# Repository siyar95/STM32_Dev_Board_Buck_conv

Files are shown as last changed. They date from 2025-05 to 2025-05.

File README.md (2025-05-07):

# STM32 Dev Board – Project 2

This project is a custom **development board** designed around the **STM32F405RGT** microcontroller.  
It includes the essential peripherals for firmware development and prototyping:

## 🔧 Features

- **STM32F405RGT** ARM Cortex-M3 microcontroller
- **USB (Device/Power)**
- **UART** interface for serial communication
- **SWD (Single Wire Debug)** header for programming and debugging
- **I2C** interface for peripheral communication
- **Buck converter** for stable and effecient 3.3V power supply

## 🧱 PCB Stackup

This project uses a 4-layer PCB design:

1. **Top Layer (Layer 1)** – Signal  
2. **Inner Layer 1 (Layer 2)** – Ground (GND)  
3. **Inner Layer 2 (Layer 3)** – 3.3V Power Plane  
4. **Bottom Layer (Layer 4)** – Signal








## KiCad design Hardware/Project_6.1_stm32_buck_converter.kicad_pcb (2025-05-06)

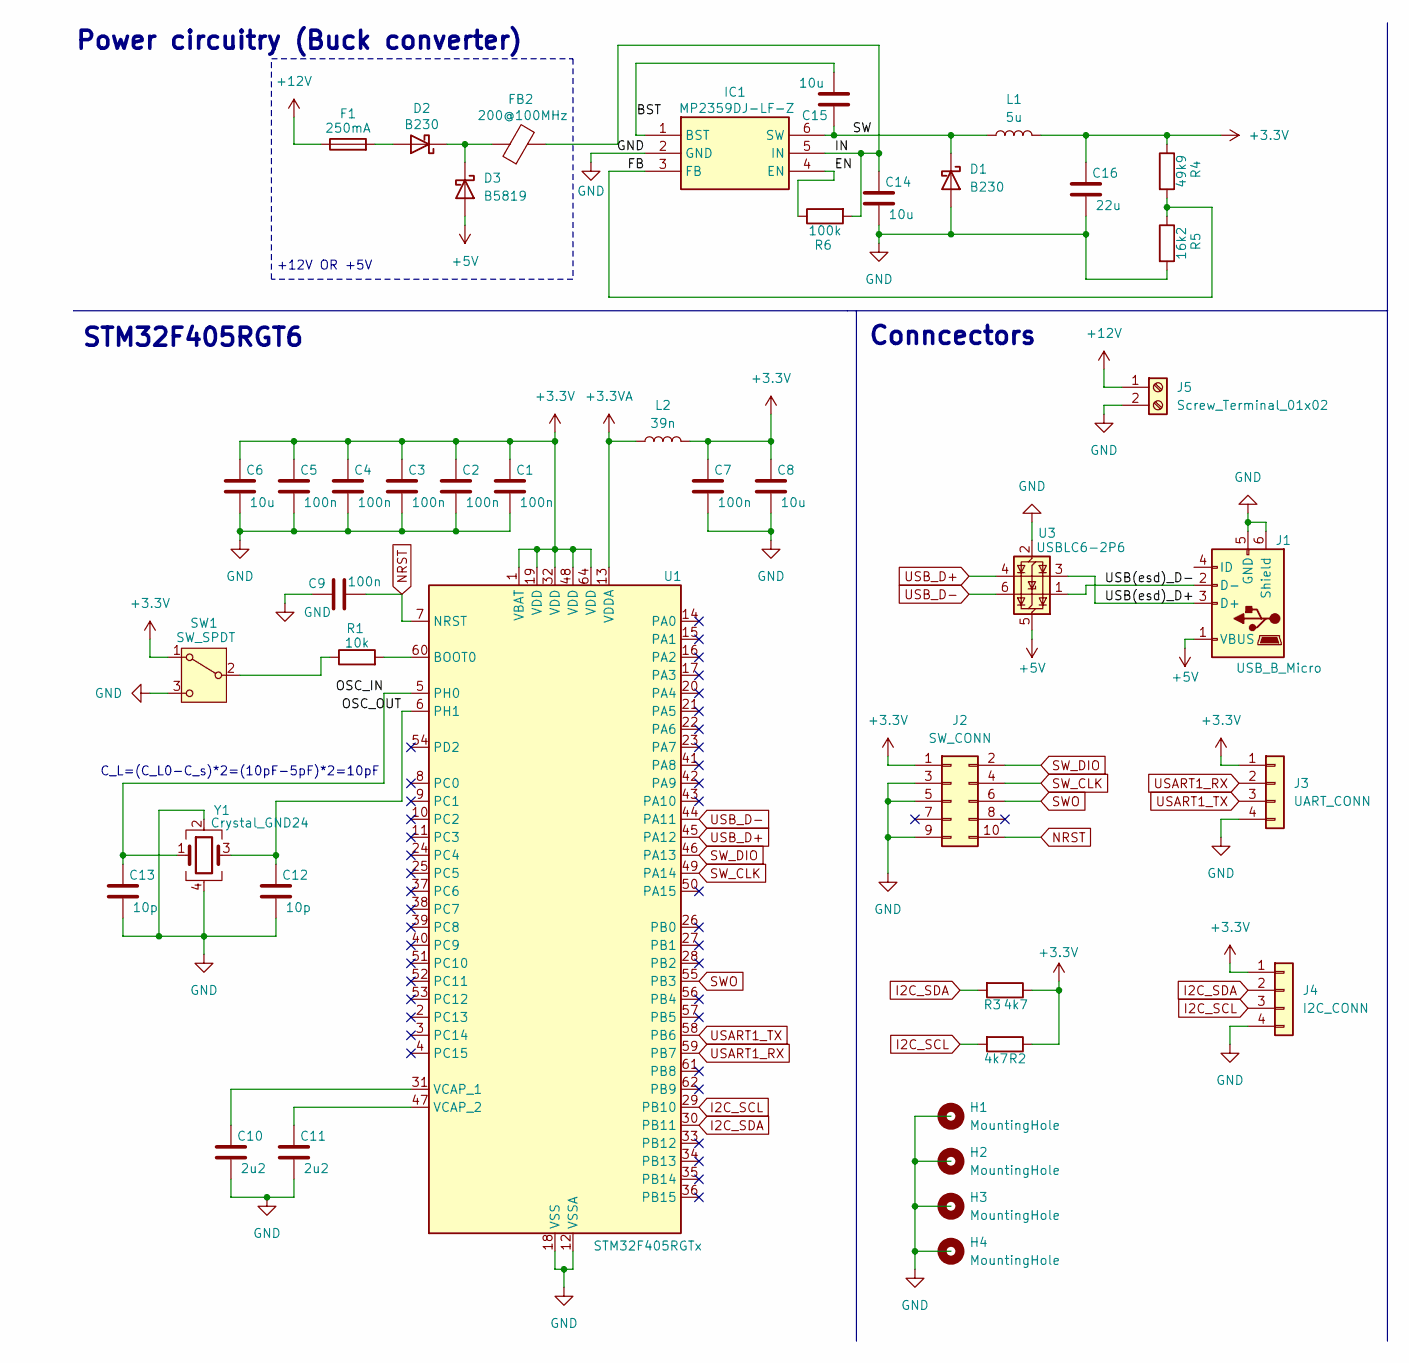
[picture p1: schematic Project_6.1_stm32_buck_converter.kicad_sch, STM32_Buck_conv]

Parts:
C1, C2, C3, C4, C5, C7, C9: 100n; C_0402_1005Metric
C6, C8, C14, C15: 10u; C_0603_1608Metric
C10, C11: 2u2; C_0603_1608Metric
C12, C13: 10p; C_0402_1005Metric
C16: 22u; C_0805_2012Metric
D1, D2: B230; D_SMB
D3: B5819; b5819
F1: 250mA; Fuse_0603_1608Metric
FB2: 200@100MHz; L_0603_1608Metric
H1, H2, H3, H4: MountingHole; MountingHole_2.2mm_M2
IC1: MP2359DJ-LF-Z; SOT95P280X100-6N; Mouser Part Number 946-MP2359DJLFZ
J1: USB_B_Micro; USB_Micro-B_Amphenol_10118193-0001LF_Horizontal
J2: SW_CONN; PinHeader_2x05_P2.54mm_Vertical
J3: UART_CONN; PinHeader_1x04_P2.54mm_Vertical
J4: I2C_CONN; PinHeader_1x04_P2.54mm_Vertical
J5: Screw_Terminal_01x02; TerminalBlock_Phoenix_MPT-0,5-2-2.54_1x02_P2.54mm_Horizontal
L1: 5u; L_0603_1608Metric
L2: 39n; L_0402_1005Metric
R1: 10k; R_0603_1608Metric
R2, R3: 4k7; R_0603_1608Metric
R4: 49k9; R_0603_1608Metric
R5: 16k2; R_0603_1608Metric
R6: 100k; R_0603_1608Metric
SW1: SW_SPDT; SW_SPDT_PCM12
U1: STM32F405RGTx; LQFP-64_10x10mm_P0.5mm
U3: USBLC6-2P6; SOT-666
Y1: Crystal_GND24; Crystal_SMD_Abracon_ABM3C-4Pin_5.0x3.2mm

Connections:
+3.3V: C1.1, C2.1, C3.1, C4.1, C5.1, C6.1, C7.1, C8.1, C16.1, J2.1, J3.1, J4.1, L1.2, L2.2, R2.1, R3.1, R4.1, SW1.1 (A), U1.1 (VBAT), U1.19 (VDD), U1.32 (VDD), U1.48 (VDD), U1.64 (VDD)
+3.3VA: L2.1, U1.13 (VDDA)
+5V: D3.2 (A), J1.1 (VBUS), U3.5 (VBUS)
+12V: F1.1, J5.1
/BST: C15.2, IC1.1 (BST)
/EN: IC1.4 (EN), R6.1
/FB: IC1.3 (FB), R4.2, R5.1
/IN: C14.1, FB2.2, IC1.5 (IN), R6.2
/OSC_IN: C13.1, U1.5 (PH0), Y1.1
/OSC_OUT: C12.1, U1.6 (PH1), Y1.3
/SW: C15.1, D1.1 (K), IC1.6 (SW), L1.1
/USB(esd)_D+: J1.3 (D+), U3.3 (I/O2)
/USB(esd)_D-: J1.2 (D-), U3.1 (I/O1)
GND: C1.2, C2.2, C3.2, C4.2, C5.2, C6.2, C7.2, C8.2, C9.1, C10.2, C11.2, C12.2, C13.2, C14.2, C16.2, D1.2 (A), IC1.2 (GND), J1.5 (GND), J1.6 (Shield), J2.3, J2.5, J2.9, J3.4, J4.4, J5.2, R5.2, SW1.3 (C), U1.12 (VSSA), U1.18 (VSS), U1.63 (VSS), U3.2 (GND), Y1.2, Y1.4
I2C_SCL: J4.3, R2.2, U1.29 (PB10)
I2C_SDA: J4.2, R3.2, U1.30 (PB11)
NRST: C9.2, J2.10, U1.7 (NRST)
unnamed: D2.2 (A), F1.2
unnamed: D2.1 (K), D3.1 (K), FB2.1
unnamed: R1.1, SW1.2 (B)
unnamed: R1.2, U1.60 (BOOT0)
unnamed: C10.1, U1.31 (VCAP_1)
unnamed: C11.1, U1.47 (VCAP_2)
SWO: J2.6, U1.55 (PB3)
SW_CLK: J2.4, U1.49 (PA14)
SW_DIO: J2.2, U1.46 (PA13)
USART1_RX: J3.2, U1.59 (PB7)
USART1_TX: J3.3, U1.58 (PB6)
USB_D+: U1.45 (PA12), U3.4 (I/O2)
USB_D-: U1.44 (PA11), U3.6 (I/O1)

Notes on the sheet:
+12V OR +5V
STM32F405RGT6
Power circuitry (Buck converter)
Conncectors
C_L=(C_L0-C_s)*2=(10pF-5pF)*2=10pF

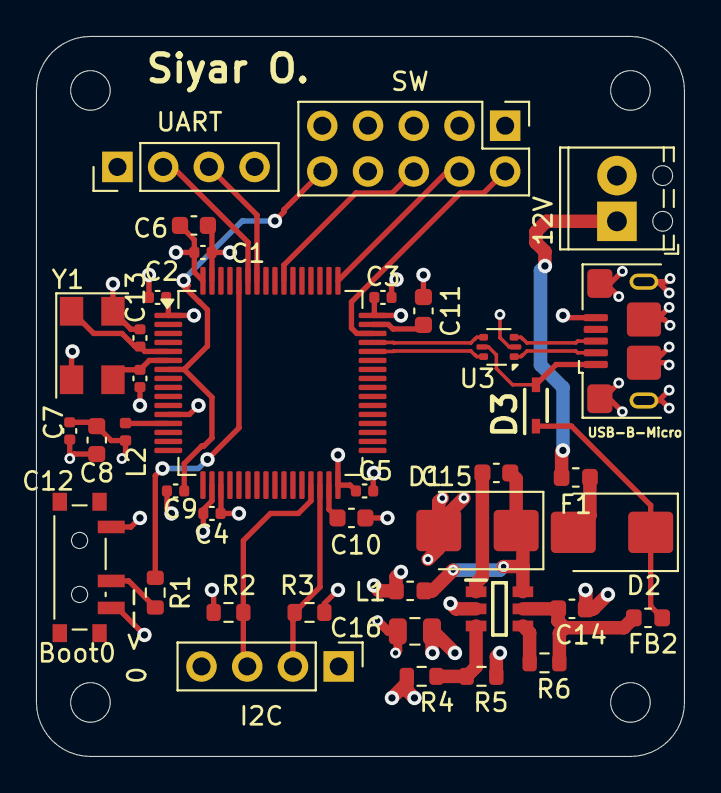
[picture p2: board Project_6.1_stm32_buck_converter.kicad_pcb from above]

Board: 4 copper layers, 36.0 x 40.0 mm, 43 parts (0 on the bottom side), 30 nets.

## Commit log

2025-05-06 Update and rename Project_6.1_stm32_buck_converter.kicad_pcb to Hardware/Project_6.1_stm32_buck_converter.kicad_pcb
    [Project_6.1_stm32_buck_converter.kicad_pcb]
2025-05-06 Update and rename Project_6.1_stm32_buck_converter.kicad_sch to Hardware/Project_6.1_stm32_buck_converter.kicad_sch
    [Project_6.1_stm32_buck_converter.kicad_sch]
